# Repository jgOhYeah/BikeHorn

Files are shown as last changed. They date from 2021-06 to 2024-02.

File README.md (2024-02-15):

# BikeHorn
A "musical" siren for bicycles.
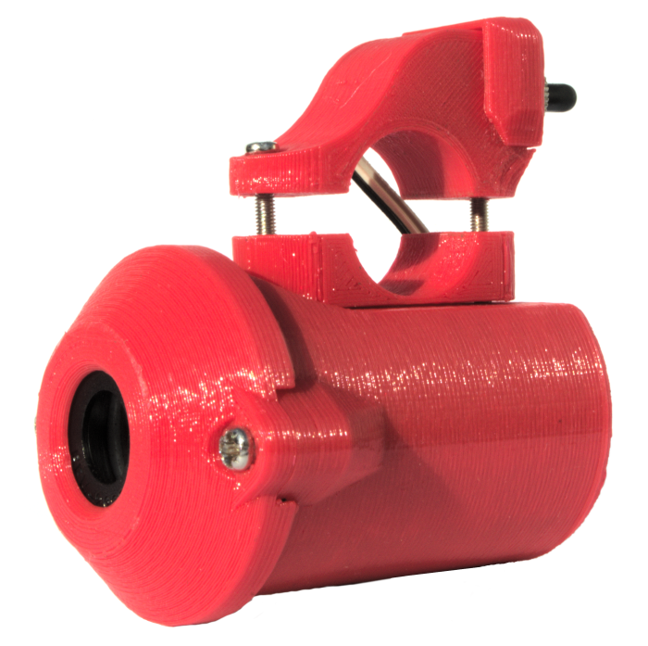
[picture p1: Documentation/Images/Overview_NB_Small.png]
Overview photo of the horn from an angle


This design was published in the Circuit Notebook section of the [Februrary 2022 issue](https://www.siliconchip.com.au/Issue/2022/February) of the Silicon Chip magazine. Feel free to have a look there if you would like a nice explanation / writeup of the horn's operations and construction.

## Main steps for building and usage
1. Modify the Arduino nano for low power and low voltage usage.
2. Build the circuit - see [BikeHornPCB](BikeHornPCB) for a PCB design. The siren is from an old smoke alarm.
3. 3D print the case.
4. Optimise parameters for each note to be the loudest possible - see [Tuning](Tuning) for details.
5. Generate the tunes to play using [this Musescore plugin](https://github.com/jgOhYeah/TunePlayer/blob/main/extras/MusescorePlugin.md). Paste this into `tunes.h` in the main [BikeHorn sketch](BikeHorn).
6. Upload to the Arduino and test.
7. Mount on bicycle / vehicle and have fun.

See the Silicon Chip section or the [Images directory](Documentation/Images) for relevent diagrams and images of the horn.

A low resolution gif that gives an idea of order of assembly:  
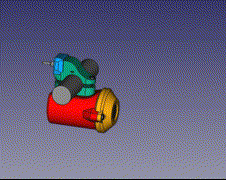
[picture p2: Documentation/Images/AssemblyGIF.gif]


## Extensions
I have attempted to make the firmware fairly modular and most non-core parts have been included as externsions. This allows for easier maintenance and customisation. For more details on enabling, disabling and writing extensions, please see the [extensions documentation](Documentation/Extensions.md).

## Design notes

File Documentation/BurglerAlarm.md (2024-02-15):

# Burgler Alarm

## State machine
```mermaid
graph TD;
    StateInit((StateInit)) -- Delay --> StateSleep
    StateSleep -- Angle / Acceleration change --> StateAwake
    StateAwake -- Otherwise --> StateAwake
    StateAwake -- Angle / Acceleration change --> StateAlert
    StateAlert -- Timeout --> StateSleep
    StateAlert -- Angle / Acceleration change --> StateCountdown
    StateCountdown -- Pin correct --> Exit((Exit))
    StateCountdown -- Timed out --> StateSiren
    StateSiren -- Pin correct --> Exit
    StateSiren -- Time out --> StateSleep
```

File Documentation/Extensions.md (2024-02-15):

# Extensions
I have attempted to make the firmware fairly modular and most non-core parts have been included as externsions. This allows for easier maintenance and customisation.

## Extensions overview
All files relating to extensions are in the `src/extensions` folder of the firmware. `extensionsManager.h` contains the framework for the extensions system and `extensions.h` includes and specifies which extensions are enabled.

## Using extensions / menu system
Each extension will behave slightly differently. Some extensions may need to have functionality activated / run on command. This is addressed through a menu system.

To enter the menu, press the change tune button for more than two seconds. The next item can be selected by short pressing the change tune button. If this button has been pressed more times than there are items, the menu will go back to the start and play a short beep. To select an item, long press the change tune button.

If at any time, the horn button is pressed, the menu will be exited and the horn will sound. This is for safety reasons to keep the horn sound available as much as possible.

## Adding and removing an extension
To add an extension, modify `extensionsManager.h`.

Include the extension header file and create an instance:
```c++
#include "exampleExtension.h"
ExampleExtension exampleExtension;
```

Add a reference to the instance to the array of extensions:
```c++
Extension* extensionsList[] = {
    &exampleExtension,
    // ... Other extension instances
};
```
The order in this array affects the order that extensions are called for each hook and the order that they appear in the menu if they have menu items.

## Existing extensions
- **[Burgler alarm](BurglerAlarm.md)** - Uses an accelerometer to sound the siren if disturbed.
- **Example extension** - Demonstrates how extensions may be implemented.
- **Log run time** - Logs how many times and for how long the horn is used to EEPROM for battery life estimates.
- **Measure battery** - Prints the battery voltage to the serial console every so often.
- **MIDI synth** - Allows the horn to function as a MIDI synth.
- **SOS** - Plays the morse SOS tone indefinitely when selected from the menu.

## Extension structure
Each extension is a class that inherits the `Extension` class. This has a number of methods that can be overridden and are called on certain events occuring, such as on startup, waking up and playing tunes.

```mermaid
classDiagram
    ExtensionManager "1" --> "1" Array
    Extension "1" --> "1" Array
    Extension "0..*" --> "1" MenuItem
    ExtensionManager "1" --> "0..*" Extension
    Extension <|-- ExampleExtension

    class Array~Type~ {
        <<struct>>
        +Type* array
        +uint8_t length
    }

    class MenuItem {
        <<typedef>>
    }

    class Extension {
        <<abstract>>
        +onStart()
        +onWake()
        +onSleep()
        +onTuneStart()
        +onTuneStop()
        +Array~MenuItem~ menuActions
    }

    class ExtensionManager {
        +callOnStart()
        +callOnWake()
        +callOnSleep()
        +callOnTuneStart()
        +callOnTuneStop()
        +displayMenu()
        -Array~Extension*~ extensions
    }

    class ExampleExtension {

    }
```

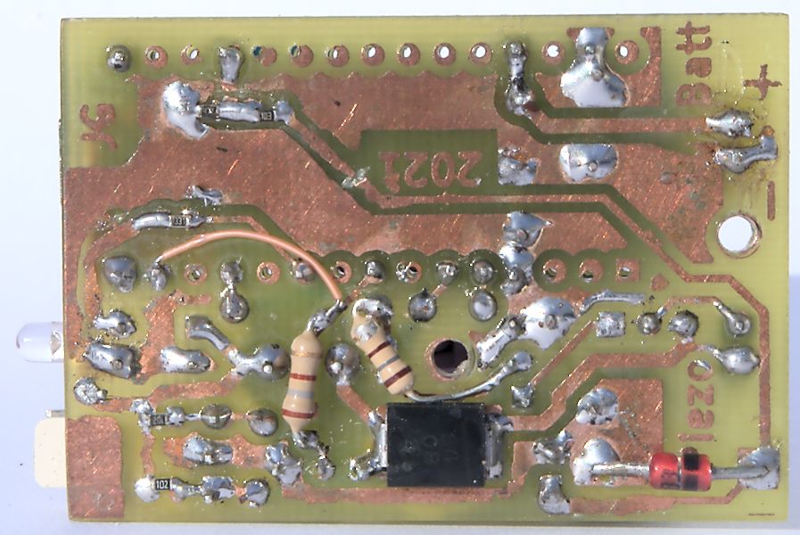
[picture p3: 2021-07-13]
Documentation/Images/PCB_Back.jpg

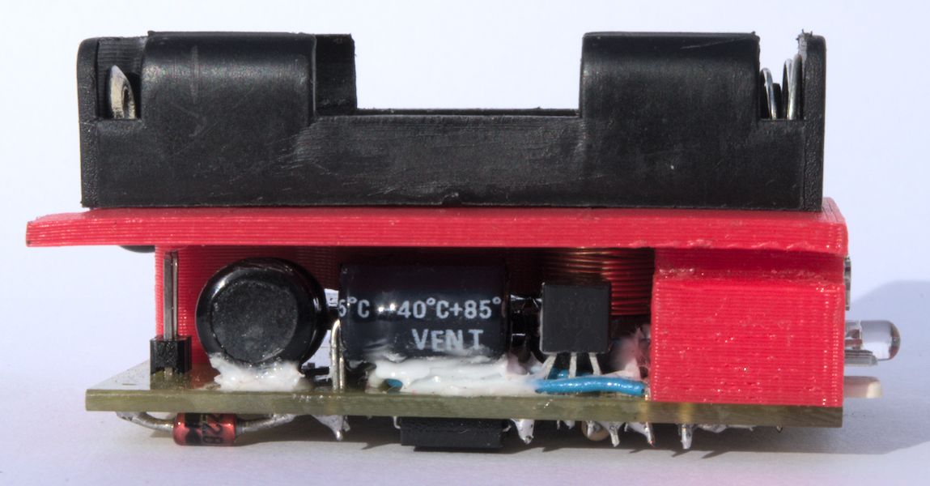
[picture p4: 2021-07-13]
Documentation/Images/Tray_Side.jpg

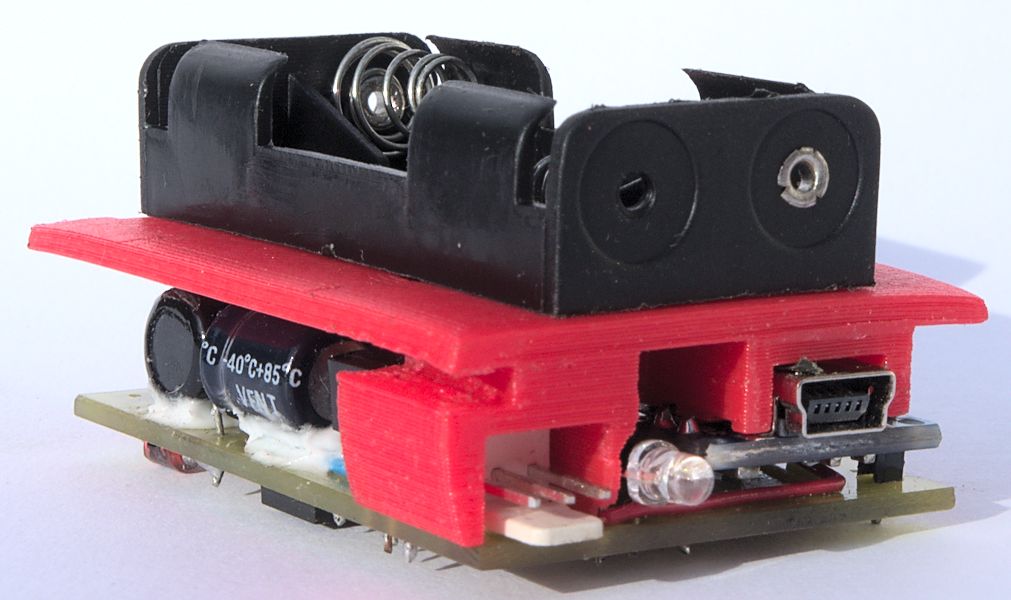
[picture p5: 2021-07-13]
Documentation/Images/Tray_Angle.jpg

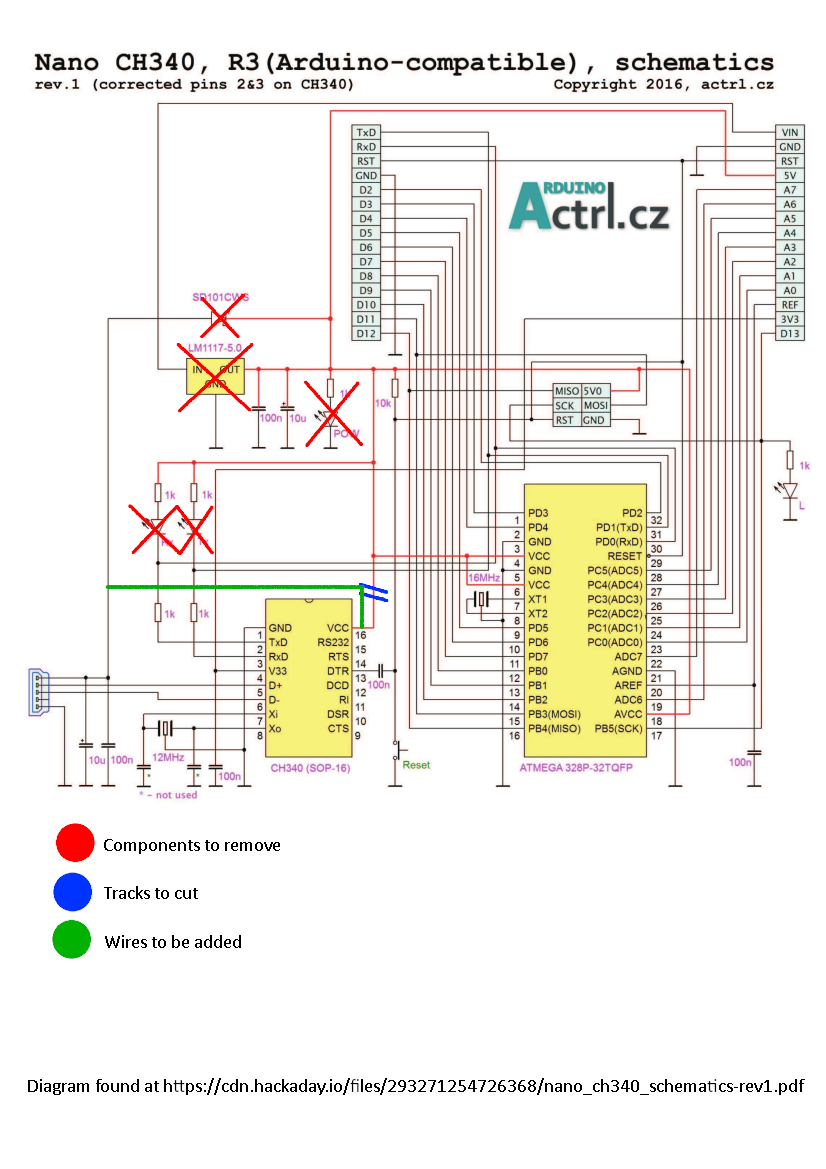
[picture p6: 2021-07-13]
Documentation/Images/ArduinoNanoModifications.png

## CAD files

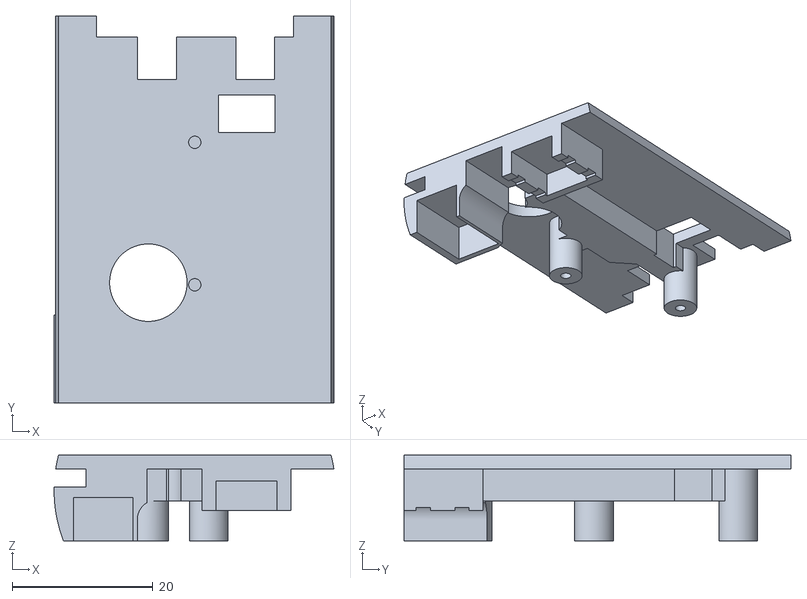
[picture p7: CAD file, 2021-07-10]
Case/MainBody-CarrierFrame.stl
39.8 x 55.0 x 12.2

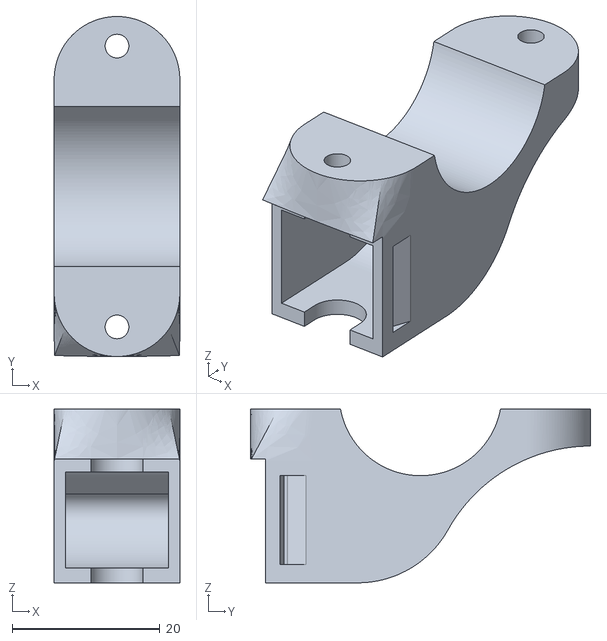
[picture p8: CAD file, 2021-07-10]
Case/MainBody-HandlebarClampSwitch.stl
17.0 x 46.0 x 23.5

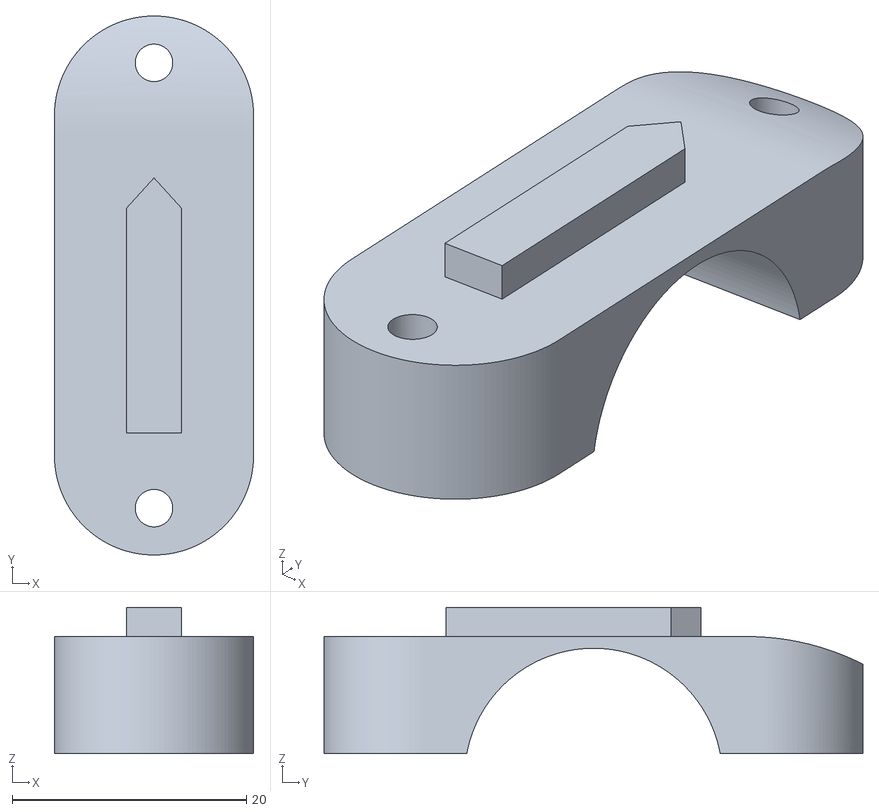
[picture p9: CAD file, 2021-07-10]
Case/MainBody-HandlebarGuide.stl
17.0 x 46.0 x 12.5

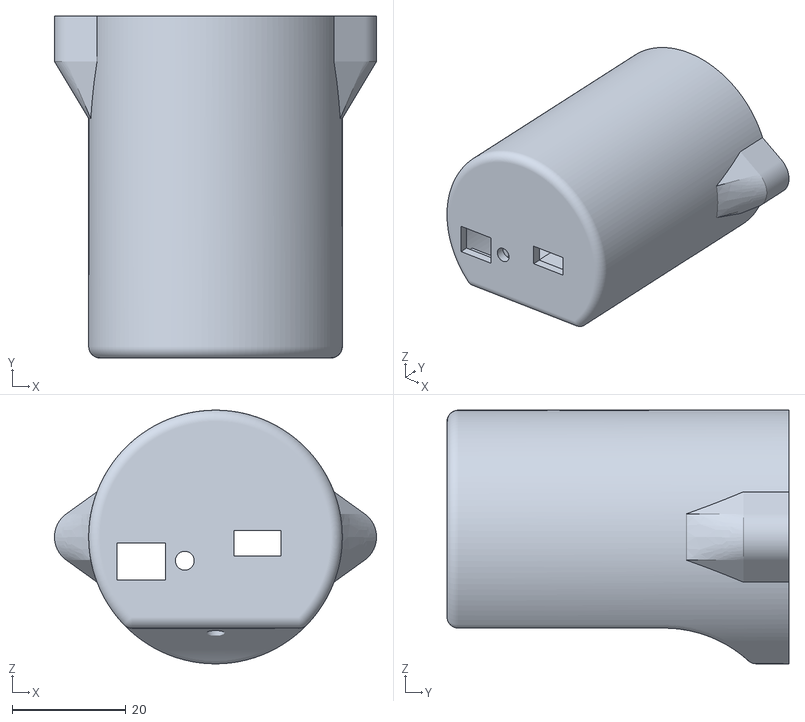
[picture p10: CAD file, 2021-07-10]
Case/MainBody-MainBody.stl
56.5 x 60.0 x 44.5

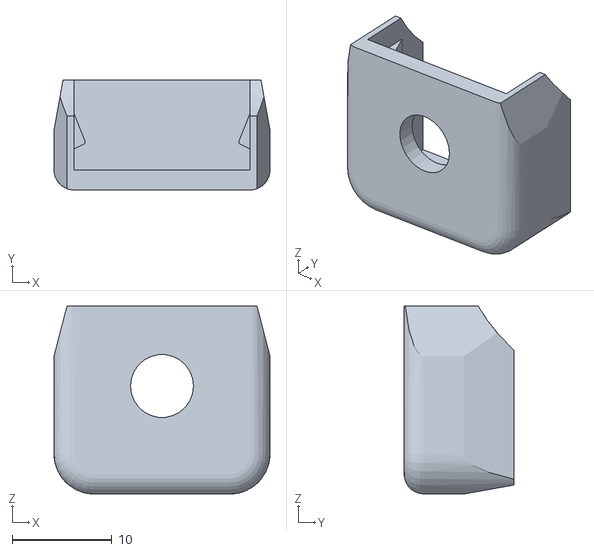
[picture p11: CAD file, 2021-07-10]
Case/MainBody-SwitchCover.stl
21.6 x 11.0 x 18.8

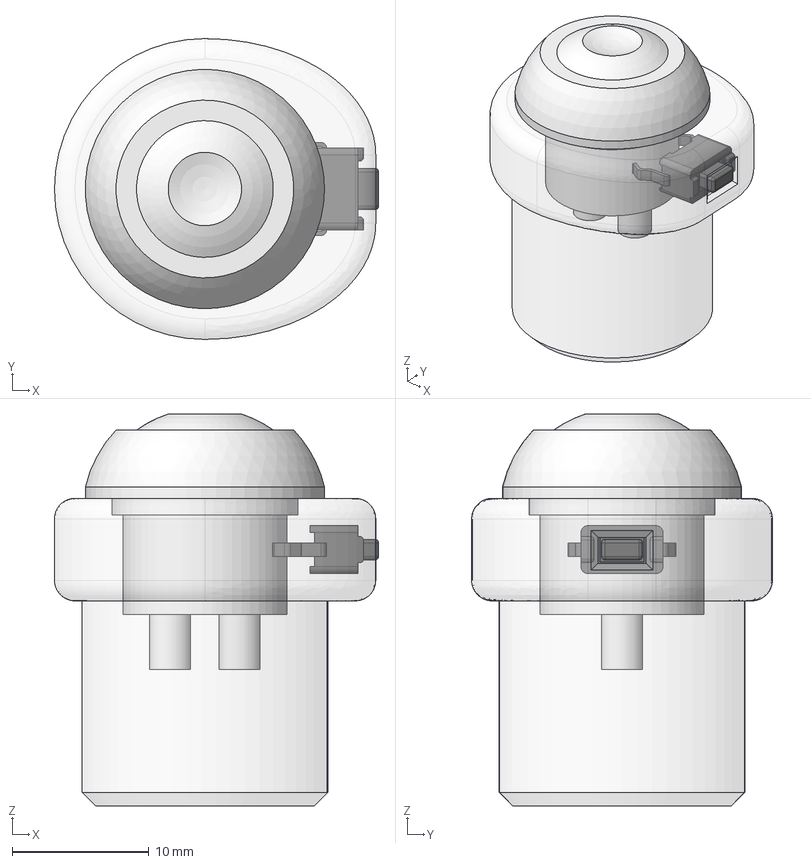
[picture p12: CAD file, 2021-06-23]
Case/HandlebarButton.FCStd
23.7 x 22.0 x 28.7 mm
Button
Mount
TactileSW

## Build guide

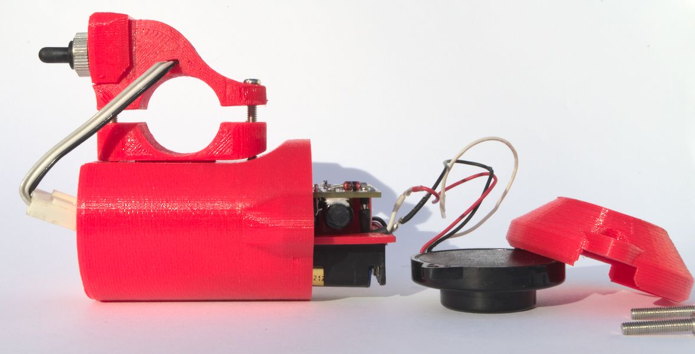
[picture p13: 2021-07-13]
Documentation/Images/PartlyDisassembled.jpg

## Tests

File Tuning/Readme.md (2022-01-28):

I find piezo sirens to be fairly fussy and unpredictable when trying to make them loud, especially across a broad range of frequencies. To help with this, I have written a small application to vary a couple of parameters under the horn's control and measure the resulting volume of the siren using a laptop / computer microphone. The data is then analysed and converted into a series of straight lines before being uploaded to the EEPROM of the Arduino in the horn.

This application is a python script and has been tested on Windows and Linux (Ubuntu), but should also work on Macintosh / other operating systems as long as the required libraries are installed.

> **Note:** This optimiser, the files it produces / uses and the way data is stored on the horn itself is in no way compatible with the earlier `SoundLevel.py` and `DisplayData.py` scripts. If you want to use or access these tools, you will need to use an [earlier release](https://github.com/jgOhYeah/BikeHorn/releases/tag/v1.0.0).

# Table of contents <!-- omit in toc -->
- [Installation](#installation)
- [Main Steps](#main-steps)
  - [Initial setup and running a test](#initial-setup-and-running-a-test)
  - [Saving and loading test results](#saving-and-loading-test-results)
  - [Interpreting and viewing test results](#interpreting-and-viewing-test-results)
  - [Optimising the test results](#optimising-the-test-results)
  - [Uploading the settings to the horn](#uploading-the-settings-to-the-horn)
  - [Tidying up and making the horn usable](#tidying-up-and-making-the-horn-usable)
- [Advanced features and debugging](#advanced-features-and-debugging)
- [Troubeshooting](#troubeshooting)
- [Questions that may or may not be asked, let alone frequently asked](#questions-that-may-or-may-not-be-asked-let-alone-frequently-asked)
# Installation
The application requires python 3 along with a few non built-in libraries. Assuming you already have python 3, the libraries can be installed with
```bash
pip3 install numpy sounddevice pyserial piecewise-regression matplotlib
```
Download this repository or at the very least [`BikeHornOptimiser.py`](BikeHornOptimiser.py) and the [corresponding Arduino sketch](OptimiserSketch).

# Main Steps
## Initial setup and running a test
1. Upload the [Optimiser Sketch](OptimiserSketch) to the horn.
2. Find a quiet place to make not very quiet for the next little while.
3. Run [`BikeHornOptimiser.py`](BikeHornOptimiser.py). In the terminal, this will be something like `python3 BikeHornOptimiser.py`. On Windows, this seems to be a little slow in starting. If no window appears, attempt to run the script from the terminal and see if there is any error messages or missing libraries reported. A window should appear looking something like this:  
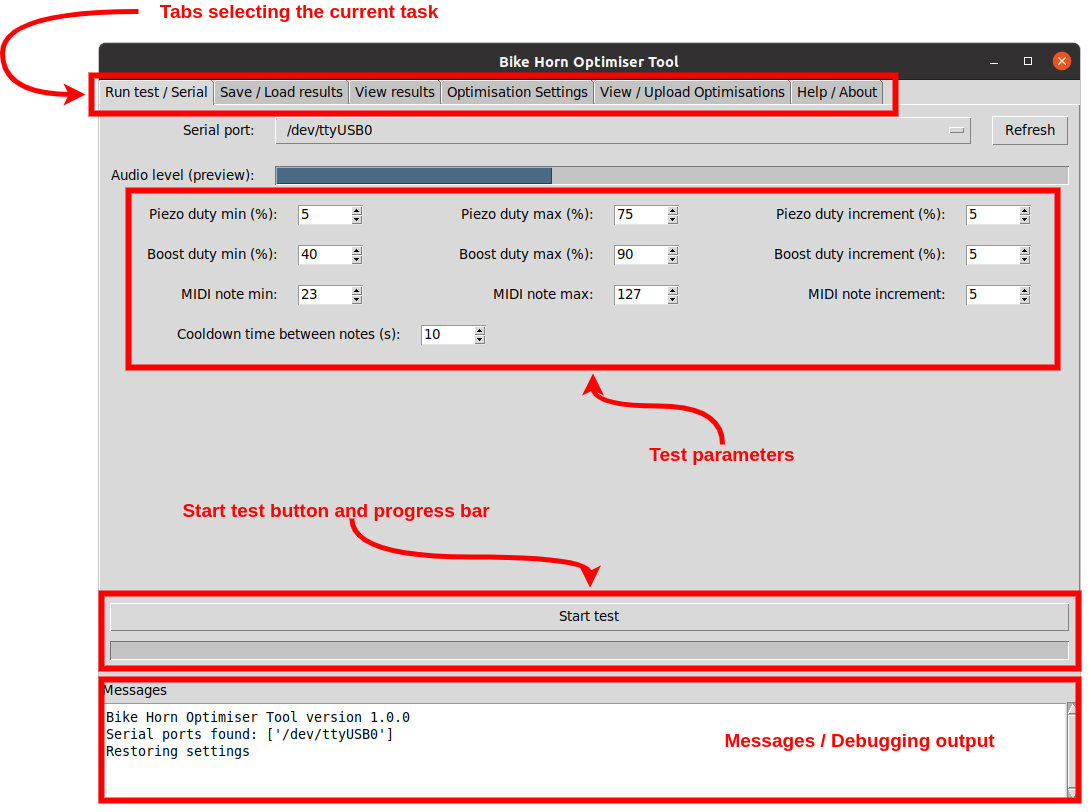
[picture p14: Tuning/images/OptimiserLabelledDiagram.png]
Labelled diagram of the bike horn optimiser application, showing the tabbed layout

4. If you have existing test data with settings you would like to reuse, open this file using the *Save / Load results* tab (see the [Saving and loading test results](#saving-and-loading-test-results).
5. Navigate to the *Run Test / Serial* tab (you will be on it by default). Connect the horn to the computer using a mini usb cable and select its serial port (something like `COM6` on Windows and `/dev/ttyUSB0` or `/dev/ttyACM0` on other operating systems). Try clicking the *Refresh* button if the serial port is not listed.
6. Edit the parameters for which to run the test with. These allow you to specify the ranges of duty cycles to test for driving the piezo siren and driving the voltage boosting stage, as well as the amount to increment these values between each test. You can also select what range of MIDI notes to test and allow the horn to cool down for a few seconds in between testing each MIDI note.
7. When ready, click *Start test*. If it is greyed out, no serial port is selected. Select the horn's serial port and try again. All going well, the horn should start making noises a few seconds later. The message box will print an estimate of the time that the test will take followed by the progress

## Saving and loading test results
Test results can be saved and loaded from a file so that the results can be analysed and uploaded at a different time to when the test is run. In case of crashes or unexpected interruptions when running a test, a backup file is saved after testing each note. This has the same name at the currently opened file (or one based off the time the application was started if nothing was opened) with "BACKUP" appended to the end.

Use the *Open* button to open a file, loading stored settings and test data and the *Save as* button to save all existing settings and test data. Opening a file will clear any existing, unsaved data.

## Interpreting and viewing test results
The *View results* tab contains a 3D surface plot for each note showing the percieved loudness as each of the two parameters of the duty cycle for the piezo element and the boost stage are varied. The optimal settings of these duty cycles are the highest point on the loudnes scale (marked by an orange dot). The scroll bar below the graph can be used to adjust the data for which note is displayed. Some notes will have a nice, clean surface such as this example:  
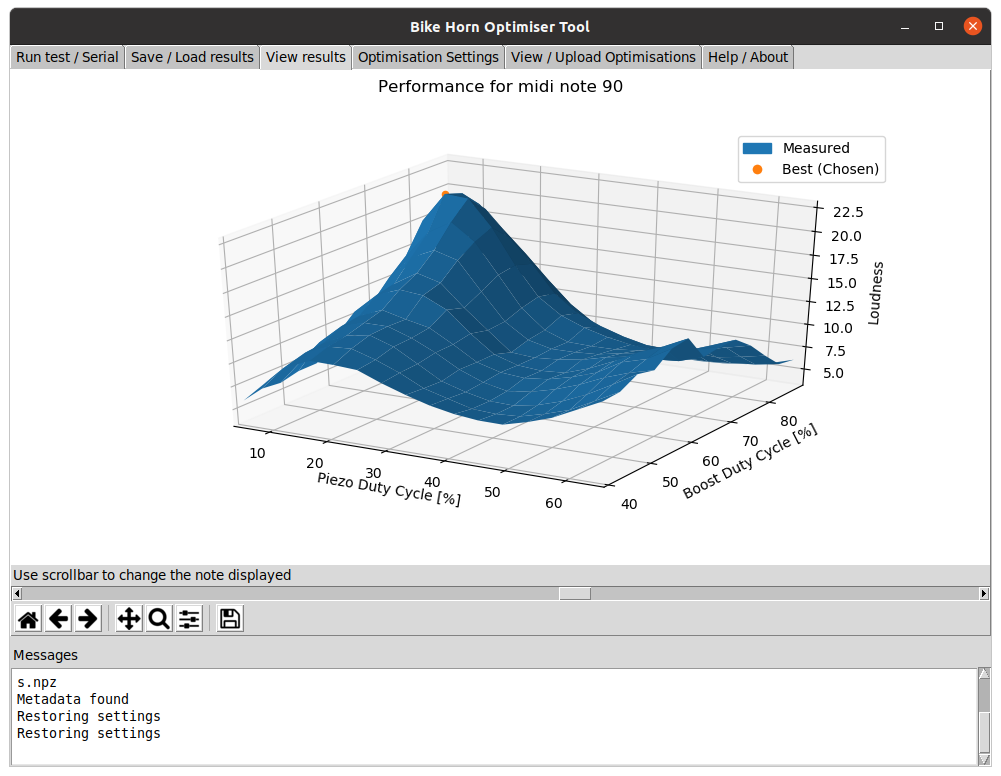
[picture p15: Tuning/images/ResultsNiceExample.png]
Screenshot of the results tab for midi note 90 of a test showing a nice smooth surface
  
Other notes appear much noisier in their data. The aim is to reduce this noise as much as possible, although I'm not quite sure how to do this at the moment apart from trying to minimise background noise during the testing process.

The *Optimisation settings* tab shows the settings picked as optimal for each midi note (i.e. the settings for the orange dot in the *View results* tab for each midi note). An example of this is shown below:  
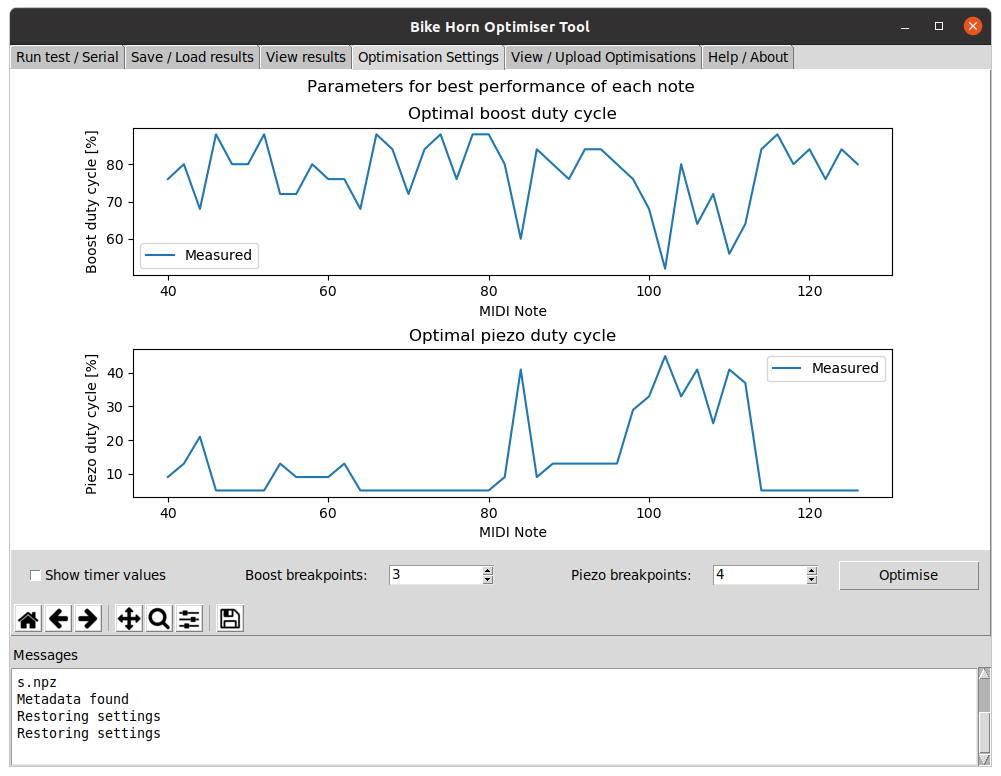
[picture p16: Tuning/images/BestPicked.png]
Screenshot of the Optimisation Settings tab showing the settings chosen as optimal for each midi note


## Optimising the test results
Once you have some testing data, navigate to the *Optimisation Settings* tab and click *Optimise*. After a few seconds, a couple of orange lines should appear, courtesy of the [piecewise-regression](https://github.com/chasmani/piecewise-regression/) library. These approximate the measured data. Feel free to play around with the number of breakpoints, set using the number entry boxes below the graph, to produce approximations that most closely match the measured data. An example is shown below:  
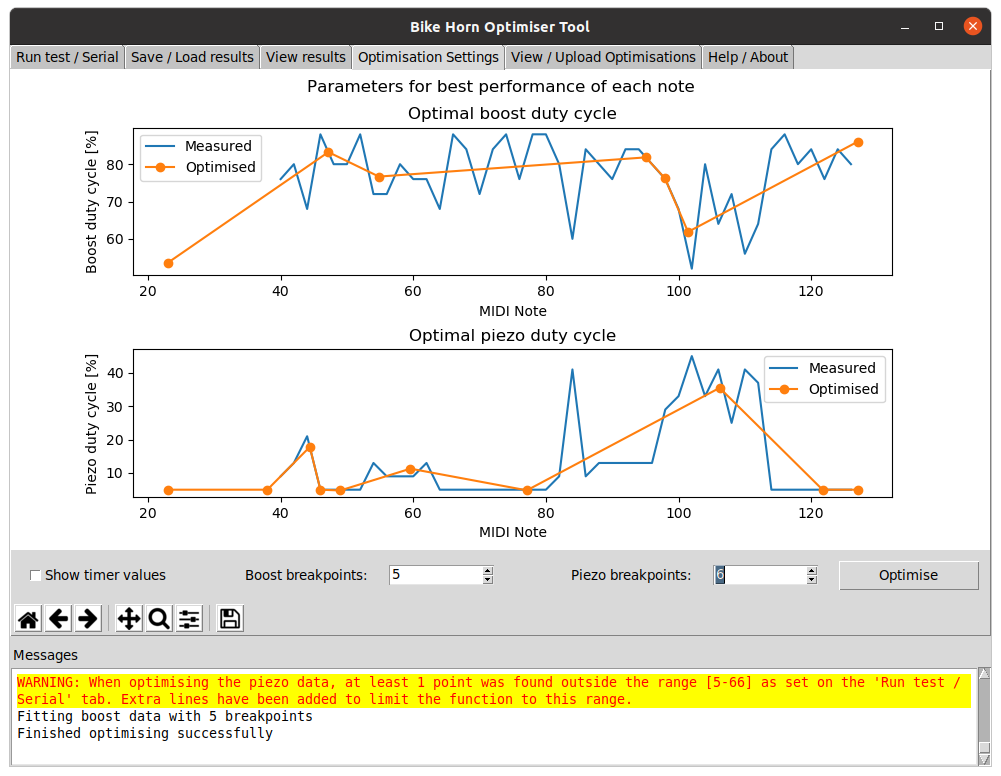
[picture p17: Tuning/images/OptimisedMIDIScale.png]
Screenshot of the optimisation window with midi scale and orange lines
  
Due to some of the randomness involved in fitting lines to the data, for higher numbers of breakpoints, it may take multiple attemts to get the results to "converge" and thus find an acceptable solution, if they do at all.

Internally, the horn uses the maximum value the piezo timer (timer 1) counts to as the x axis instead of the midi note and the compare value for the relevent timer instead of the duty cycle. If you would like to view the data using these scales, tick the *Show timer values* checkbox belows the graphs. An extra green line will be displayed on each graph. This represents the actual linear lines that will be uploaded to the horn, allowing for integer maths and limited space available to store the relevent numbers. An example is shown below:  
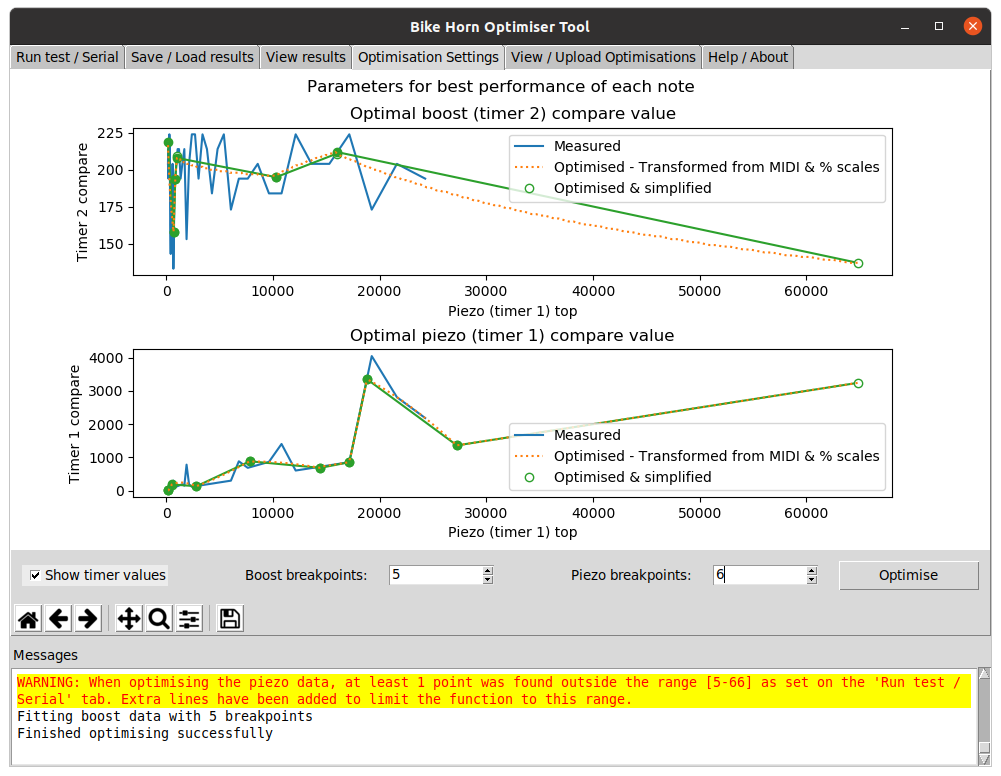
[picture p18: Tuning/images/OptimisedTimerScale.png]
Screenshot of the optimisation window with midi scale and orange and green lines


## Uploading the settings to the horn
As shown below, the top two text boxes in the *View / Upload optimisations* tab show my attempt at drawing piecewise function representations of the settings that will be uploaded. The final text box shows the raw data that will be uploaded to the EEPROM in the horn, mainly for curiosity's sake.  
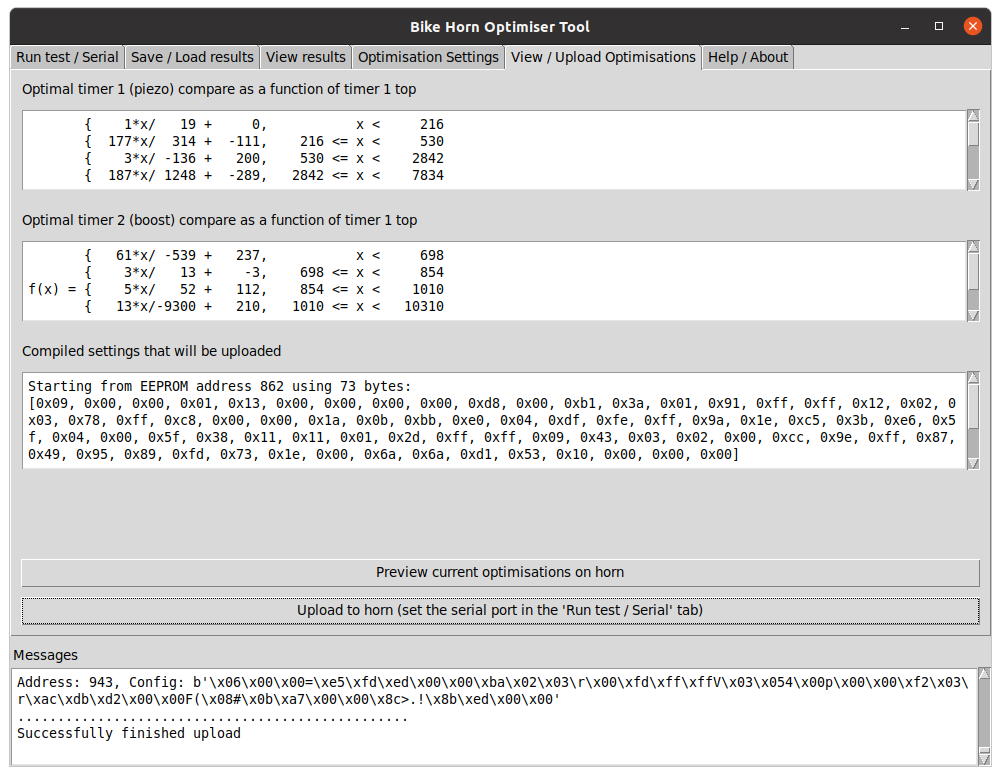
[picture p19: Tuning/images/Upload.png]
Screenshot of the upload tab showing the text boxes with the piecewise functions and raw data to upload


Make sure the horn is connected and the serial port is set correctly on the *Run test / Serial* tab. Now click the *Upload to horn* button. All going well, the settings will be uploaded to the horn.

## Tidying up and making the horn usable
Flash the main [bike horn sketch](../BikeHorn/) to make the horn usable again and to put it back into power saving mode so that it will not flatten any installed batteries if left sitting for too long.

# Advanced features and debugging
## Previewing settings before uploading them <!-- omit in toc -->
A preview tool has been included to allow easier experimentation with settings before uploading them to the horn's EEPROM. This can be accessed from the *Preview current optimisations on horn* button in the *View / Upload optimisations* tab. This will display a new window as shown below, allowing single notes or a range of midi notes to be played with selectable duty cycles for the piezo element and boost stage.  
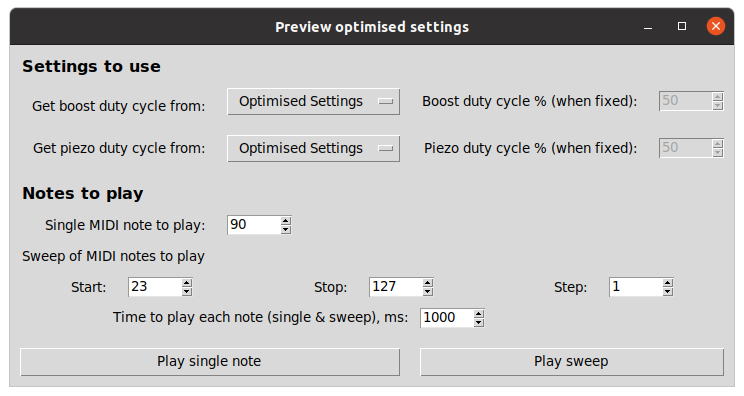
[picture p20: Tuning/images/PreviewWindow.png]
Screenshot of the preview window


## Dumping the contents of the EEPROM <!-- omit in toc -->
Connect the horn and click the *Dump EEPROM of a connected horn* button in the *Help / About* tab.

## Erasing the EEPROM <!-- omit in toc -->
Connect the horn and click the *Wipe EEPROM of a connected horn* button in the *Help / About* tab.

# Troubeshooting
## The serial port does not appear <!-- omit in toc -->
Check whether other software such as the Arduino IDE can see the serial port. Make sure no other programs have it open or are currently using it.

## "Did not get a response from the horn" message <!-- omit in toc -->
Are you using the correct serial port and is the [Optimiser sketch](OptimiserSketch/) uploaded to the horn? Also make sure no other software is currently using the serial port. If this doesn't work, try unplugging and replugging in the usb cable.

## Arduino not resetting or misbehaving after using this application <!-- omit in toc -->
Try unplugging and replugging in the usb cable.
## Application freezes when trying to close it <!-- omit in toc -->
This is a bug I have not worked out yet - something to do with the audio level monitoring. If you are running the application in a terminal, try using *Control-C* a couple of times. If that doesn't work or you aren't using a terminal, kill the program using the task manager.

# Questions that may or may not be asked, let alone frequently asked
## Why store the optimised settings in EEPROM? <!-- omit in toc -->
The original optimisation scripts outputted C++ code to paste into the [Bike horn Arduino sketch](../BikeHorn). While this does work for one horn, I could see this becoming a problem if more than one horn is ever built, as you would end up with code that needs to be customised for each horn and then kept track of through updates and changing of the installed tunes, making it messy to deal with. Instead, the aim of storing the optimised settings in EEPROM is that the settings live with the horn rather than the source code, meaning that the same source code can theoreticaly be used with every horn in existance and they should all perform optimally as far as selecting the best duty cycles of each stage. Tunes may still need to be transposed to suit each horn's preferred frequency range though.

## Why is the optimising sketch not a part of the main bike horn sketch? <!-- omit in toc -->
The aim of optimising is that it doesn't need to be done all that often. Seeing as the tunes are stored as part of the program, the horn will need to be reprogrammed whenever the installed tunes are uploaded, so it is not much of an extra burden to upload a special optimising sketch. It is also one less thing to potentially go wrong in the main sketch and besides, it allows even more room for tunes 😉.

## Why the limit of 10 lines (9 breakpoints) per parameter to optimise? <!-- omit in toc -->
The processed optimisations are stored in EEPROM in the Arduino microcontroller on the horn. This is limited to 1024 bytes on an Arduino Nano. Each linear function takes up 8 bytes. Because (as an optional feature) the EEPROM is also used for tracking the number of times and for how long the horn is used for battery life monitoring, this resource needs to be shared. Feel free to adjust the parameters for the amount and addresses to allocate in the source code of this optimiser and 'defines.h' of the main bike horn sketch, making sure that they are in agreement for things to work as expected.

## Why did the battery go flat after optimising? <!-- omit in toc -->
Unlike the main bike horn sketch, she optimiser sketch does not contain any power saving features. Thus, when taking a break or leaving the horn sit, make sure to reflash the main [bike horn sketch](../BikeHorn) or take the batteries out.

## Why is the lowest midi note 23? <!-- omit in toc -->
This is due to the internal hardware and setup of the timers in the horn. Timer 1 is used to provide the frequency of the note to play by starting from 0 and counting up to a specified number before resetting back to 0. The time for this to happen is the period of the wave and thus the lower the note, the larger this number must be. Timer 1 is a 16 bit timer, meaning the maximum value it can count up to is *2^16-1 = 65535*, meaning that without mucking around with prescalars and clock speeds, midi note 23 is the lowest note where the value to count to is below 65535.

Note that this is a very low note for a piezo siren and is more a series of clicks anyway - not much use for a horn, let alone anything lower.

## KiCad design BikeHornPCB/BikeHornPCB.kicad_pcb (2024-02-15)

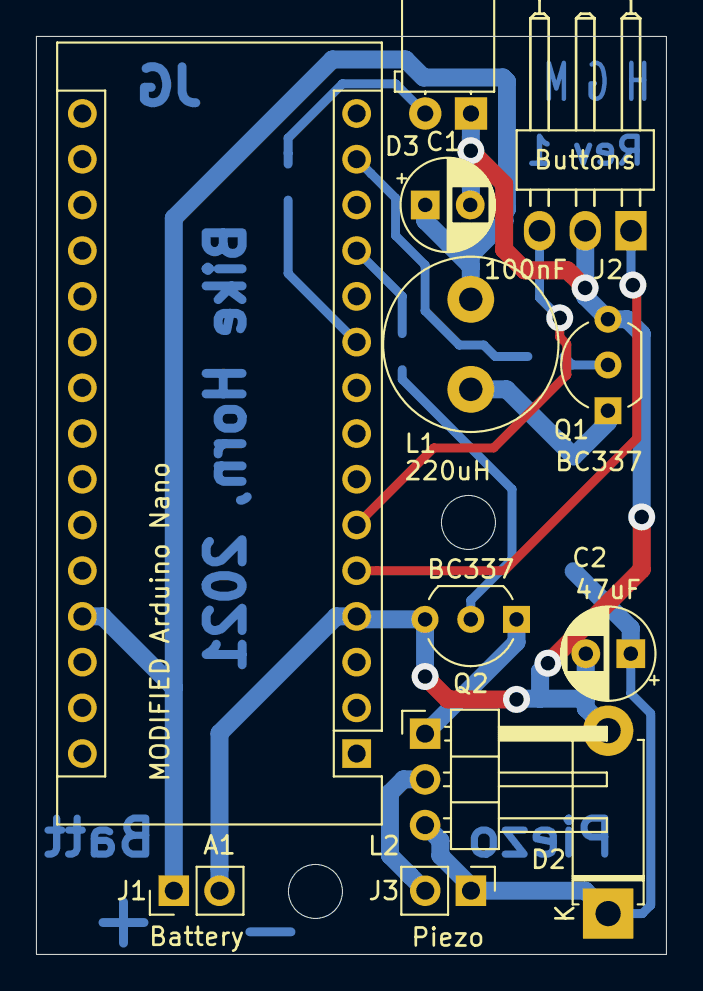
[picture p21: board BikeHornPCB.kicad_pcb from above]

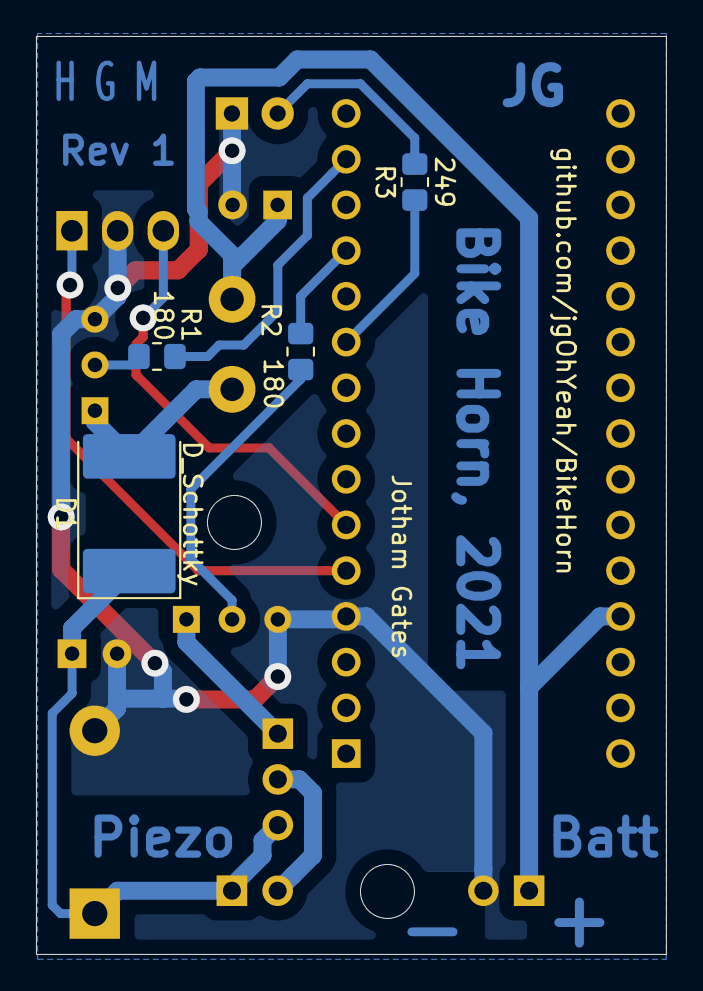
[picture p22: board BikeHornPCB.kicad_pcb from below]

Board: 2 copper layers, 35.0 x 51.0 mm, 16 parts (4 on the bottom side), 14 nets.

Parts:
A1: MODIFIED Arduino Nano; Arduino_Nano
C1: 100nF; CP_Radial_D5.0mm_P2.50mm
C2: 47uF; CP_Radial_D5.0mm_P2.50mm
D1: D_Schottky; D_3220_8050Metric
D2: 22V; D_5W_P10.16mm_Horizontal
D3: LED; LED_D5.0mm_Horizontal_O1.27mm_Z3.0mm
J1: Battery; PinHeader_1x02_P2.54mm_Vertical
J2: Buttons; Molex_KK-254_1x03_P2.54mm_Horizontal
J3: Piezo; PinHeader_1x02_P2.54mm_Vertical
L1: 220uH; L_Radial_D9.5mm_P5.00mm_Fastron_07HVP
L2: PiezoDriverCoil; PinHeader_1x03_P2.54mm_Horizontal
Q1, Q2: BC337; TO-92_Inline_Wide
R1, R2: 180; R_0805_2012Metric_Pad1.20x1.40mm_HandSolder
R3: 249; R_0805_2012Metric_Pad1.20x1.40mm_HandSolder

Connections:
+BATT: A1.27, C1.1, J1.1, L1.1
GND: A1.4, C1.2, C2.2, D2.2, D3.1, J1.2, J2.2, Q1.3, Q2.3
unnamed: A1.5, J2.1
unnamed: A1.6, J2.3
unnamed: A1.10, R3.1
unnamed: A1.12, R2.2
unnamed: A1.14, R1.2
unnamed: C2.1, D1.1, D2.1, J3.1, L2.3
unnamed: D1.2, L1.2, Q1.1
unnamed: D3.2, R3.2
unnamed: J3.2, L2.2
unnamed: L2.1, Q2.1
unnamed: Q1.2, R1.1
unnamed: Q2.2, R2.1

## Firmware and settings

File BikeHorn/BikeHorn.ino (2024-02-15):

/** BikeHorn.ino
 * Source code for the BikeHorn.
 * 
 * For more details, see README.md or go to
 * https://github.com/jgOhYeah/BikeHorn
 * 
 * Written by Jotham Gates
 * Last modified 27/01/2023
 * 
 * Requires these libraries (can be installed through the library manager):
 *   - Low-Power (https://github.com/rocketscream/Low-Power) - Shuts things down to save power.
 *   - TunePlayer (https://github.com/jgOhYeah/TunePlayer) - Does most of the heavy lifting playing the tunes.
 *   - Queue (https://github.com/SMFSW/Queue) - Required by TunePlayer.
 * 
 * Only required if LOG_RUN_TIME is defined:
 *   - EEPROMWearLevel (https://github.com/PRosenb/EEPROMWearLevel) - Logs to EEPROM.
 */

#include "defines.h"

// Prototypes so that the extension manager is happy
void uiBeep(uint16_t* beep);
void uiBeepBlocking(uint16_t* beep);
void revertToTune();
uint32_t modeButtonPress();
void startBoost();
inline void stopBoost();
void sleepGPIO();
void wakeGPIO();

#include "tunes.h"
#include "src/optimisations.h"
#include "src/soundGeneration.h"
#include "src/soundGenerationStatic.h"

FlashTuneLoader flashLoader;
BikeHornSound piezo;
TunePlayer tune;
uint8_t curTune = 0;
period_t sleepTime = SLEEP_FOREVER;

#ifdef ENABLE_WARBLE
Warble warble;
extern void uiBeep();
#endif

volatile Buttons wakePin;

#include "src/extensions/extensions.h"

void setup() {
    WATCHDOG_ENABLE;
    sleepGPIO(); // Shutdown the timers if the horn crashed previously
    wakeGPIO();
    Serial.println(F(WELCOME_MSG));
    Serial.print(F("There are "));
    Serial.print(tuneCount);
    Serial.println(F(" tunes installed"));

    // Tune Player
    flashLoader.setTune((uint16_t*)pgm_read_word(&(tunes[curTune])));
    tune.begin(&flashLoader, &piezo);
    tune.spool();

    // Extensions
    extensionManager.callOnStart();

#ifdef ENABLE_WARBLE
    /// Warble mode
    warble.begin(&piezo, WARBLE_LOWER, WARBLE_UPPER, WARBLE_RISE, WARBLE_FALL);
#endif
}

void loop() {
    // Go to sleep if not pressed and wake up when a button is pressed
    if(!IS_PRESSED(BUTTON_HORN)) {
        // Wait for tune (beep) to finish before sleeping.
        while(tune.isPlaying()) {
            tune.update();
            WATCHDOG_RESET;
            if (IS_PRESSED(BUTTON_HORN)) {
                // On rare occasions when the button is pressed during a beep, go to sleep and wake up again quickly.
                tune.stop();
                break;
            }
        }
        Serial.println(F("Going to sleep"));
        extensionManager.callOnSleep();
        sleepGPIO();
        wakeUpEnable();
        WATCHDOG_DISABLE;
        LowPower.powerDown(sleepTime, ADC_OFF, BOD_OFF); // The horn will spend most of its life here
        wakeUpDisable();
        WATCHDOG_ENABLE;
        wakeGPIO();
        Serial.println(F("Waking up"));
        extensionManager.callOnWake();
    } else {
        wakePin = PRESSED_HORN;
    }

    // If we got here, a button was pressed
    if(wakePin == PRESSED_HORN) {
        // Play a tune
        extensionManager.callOnTuneStart();
        // Start playing
        startBoost();
#ifdef ENABLE_WARBLE
        if(curTune != tuneCount) {
            // Normal tune playing mode
            tune.play();
        } else {
            // Warble mode
            warble.start();
        }
#else
        tune.play();
#endif

        // Play until the button has not been pressed in the past DEBOUNCE_TIME ms.
        digitalWrite(LED_EXTERNAL, HIGH);
        bool ledState = true;

        uint32_t startTime = millis();
        uint32_t curTime;
        uint32_t ledStart = startTime;
        do {
            WATCHDOG_RESET;

#ifdef ENABLE_WARBLE
            // Update warbling or the tune
            if(curTune != tuneCount) {
                tune.update();
            } else {
                warble.update();
            }
#else
            // Update the tune
            tune.update();
#endif

            // Flash the LED every so often
            if(curTime - ledStart > 125) {
                ledStart = curTime;
                digitalWrite(LED_EXTERNAL, !ledState);
                ledState = !ledState;
            }

            // Check if the button is pressed and reset the time if it is.
            if(IS_PRESSED(BUTTON_HORN)) {
                startTime = curTime;
            }
            curTime = millis();
        } while (curTime - startTime < DEBOUNCE_TIME);

        // Stop playing the tune
#ifdef ENABLE_WARBLE
        if(curTune != tuneCount) {
            tune.stop();
            tune.spool();
        } else {
            warble.stop();
        }
#else
        tune.stop();
        tune.spool();
#endif
        extensionManager.callOnTuneStop();

    } else if (wakePin == PRESSED_MODE) {
        // Change tune as the other button is pressed
        digitalWrite(LED_EXTERNAL, HIGH);

        // Only let go once button is not pushed for more than DEBOUNCE_TIME
        uint32_t pressTime = modeButtonPress();

        // Was this a long or short press?
        if (pressTime < LONG_PRESS_TIME) {
            // Short press, change tune
            curTune++;
#ifdef ENABLE_WARBLE
            if(curTune > tuneCount) { // Use == for the warble mode
                curTune = 0;
            }
            if(curTune != tuneCount) {
                // Change tune as normal
#else
            if(curTune == tuneCount) {
                curTune = 0;
            }
#endif
                Serial.print(F("Changing to tune "));
                Serial.println(curTune);
                flashLoader.setTune((uint16_t*)pgm_read_word(&(tunes[curTune])));

                // Stop tune and setup for the next time
                tune.stop();
                tune.spool();
#ifdef ENABLE_WARBLE
            } else {
                // Don't do anything here and select on the fly
                Serial.println(F("Changing to warble mode"));
            }
#endif
        } else {
            // Long press, display menu for extensions
            extensionManager.displayMenu();
        }
    }
}

/**
 * Puts the GPIO into a low power state ready for the microcontroller to sleep.
 */
void sleepGPIO() {
    // Shut down timers to release pins
    TCCR1A = 0;
    TCCR1B = 0;
    stopBoost();

    // Shutdown serial so it won't be affected by playing with the io lines
    Serial.end();

    // Using registers so everything can be done at once easily.
    DDRB = bit(PB1) | bit(PB3); // Set everything except pwm to input pullup
#ifdef ACCEL_INSTALLED
    DDRC = ACCEL_PINS_SLEEP_MODE;
    PORTC = ACCEL_PINS_SLEEP_STATE; // Pull up unusec inputs, set everything else low.
#else
    DDRC = 0;
    PORTC = 0xff;
#endif

    // Pull all unused pins high to avoid floating and reduce power.
    DDRD = 0x03; // Set serial as an output to tie low
    PORTB = ~(bit(PB1) | bit(PB3));
    PORTD = 0xfc; // Don't pull the serial pins high
    
    // Keep as outputs
    pinMode(LED_EXTERNAL, OUTPUT);
    pinMode(LED_BUILTIN, OUTPUT);
    digitalWrite(LED_EXTERNAL, LOW);
    digitalWrite(LED_BUILTIN, LOW);
}

/**
 * Wakes and sets up the GPIO and peripheries.
 */
void wakeGPIO() {
    DDRD = 0x02; // Serial TX is the only output
    PORTD = 0x0E; // Idle high serial
    Serial.begin(SERIAL_BAUD);
    DDRB = bit(PB1) | bit(PB3);
    PORTB = 0x00; // Make sure everything is off
    pinMode(LED_EXTERNAL, OUTPUT);
    pinMode(LED_BUILTIN, OUTPUT);

    // Will leave waking the accelerometer up to its own code as it isn't needed often.
}

void wakeUpEnable() {
    wakePin = PRESSED_NONE;
    // Set interrupts to wake the processor up again when required
    attachInterrupt(digitalPinToInterrupt(BUTTON_HORN), wakeUpHornISR, LOW);
    attachInterrupt(digitalPinToInterrupt(BUTTON_MODE), wakeUpModeISR, LOW);
}

void wakeUpDisable() {
    detachInterrupt(digitalPinToInterrupt(BUTTON_HORN));
    detachInterrupt(digitalPinToInterrupt(BUTTON_MODE));
}

/**
 * Interrupt Service Routine (ISR) called when the hirn wakes up with the horn button pressed.
 */
void wakeUpHornISR() {
    wakePin = PRESSED_HORN;
}

/**
 * Interrupt Service Routine (ISR) called when the hirn wakes up with the mode button pressed.
 */
void wakeUpModeISR() {
    wakePin = PRESSED_MODE;
}

/**
 * Sets up and starts the intermediate boost stage.
 */
void startBoost() {
    // Set PB3 to be an output (Pin11 Arduino UNO)
    DDRB |= (1 << PB3);
    
    TCCR2A = (1 << COM2A1) | (1 << WGM21) | (1 << WGM20); // Mode 3, fast PWM, reset at 255
    TCCR2B = (1<< CS20); // Prescalar 1
    OCR2A = IDLE_DUTY; // Enough duty cycle to keep the voltage on the second stage at a reasonable level.
}

/**
 * @brief Stops timer 2, which controls the boost stage.
 * 
 */
inline void stopBoost() {
    TCCR2A = 0;
    TCCR2B = 0;
}

/**
 * @brief Waits until the mode button has been released and returns the time
 * it was pressed in ms. If the horn button is pressed at any time, returns 1.
 * 
 * @return uint32_t 
 */
uint32_t modeButtonPress() {
    // Only let go once button is not pushed for more than DEBOUNCE_TIME
    uint32_t pressTime = millis();
    uint32_t debounceTime = pressTime;
    while(millis() - debounceTime < DEBOUNCE_TIME) {
        WATCHDOG_RESET;
        tune.update();
        if(IS_PRESSED(BUTTON_MODE)) {
            debounceTime = millis();
        }

        // If the horn button is pressed, exit immediately to start playing a tune.
        if(IS_PRESSED(BUTTON_HORN)) {
            wakePin = PRESSED_HORN;
            return 1;
        }
    }
    return millis() - pressTime;
}

/**
 * @brief Stores the current tune, then starts playing a beep / other tune.
 * When this is finished, the original tune will be restored.
 * 
 * @param beep the new tune.
 */
void uiBeep(uint16_t* beep) {
    tune.stop();
    tune.setCallOnStop(revertToTune);
    flashLoader.setTune(beep);
    tune.play();
}

/**
 * @brief Calls uiBeep and waits untill the tune it done.
 * 
 * // TODO: This will probably need to be adapted / removed when button input is added.
 * 
 * @param beep 
 */
void uiBeepBlocking(uint16_t* beep) {
    uiBeep(beep);
    while(tune.isPlaying()) {
        tune.update();
        WATCHDOG_RESET;
    }
}

/**
 * @brief Reverts the current tune to the selected one.
 * 
 */
void revertToTune() {
    tune.setCallOnStop(NULL);
    tune.stop();
    // If in warble, mode, don't do anything as the flashLoader object isn't used for that and will be set before next use.
#ifdef ENABLE_WARBLE
    if(curTune != tuneCount) {
        // Normal tune playing mode
        flashLoader.setTune((uint16_t*)pgm_read_word(&(tunes[curTune])));
        tune.spool();
    }
#else
    flashLoader.setTune((uint16_t*)pgm_read_word(&(tunes[curTune])));
#endif
}

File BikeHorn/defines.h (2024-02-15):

/** defines.h
 * Definitions and settings for the BikeHorn.
 * 
 * For more details, see README.md or go to
 * https://github.com/jgOhYeah/BikeHorn
 * 
 * Written by Jotham Gates
 * Last modified 27/06/2023
 */

#pragma once
#define VERSION "1.4.1"

/**
 * @brief Pins and system setup
 * 
 */
#define PIEZO_PIN 9 // Fixed as PB1 (Pin 9 on Arduino Nano)
#define BOOST_PIN 11 // Fixed as PB3 (Pin 11 on Arduino Nano)
#define LED_EXTERNAL 7
#define BUTTON_HORN 2 // Needs to be interrupt capable (pin 2 or 3)
#define BUTTON_MODE 3 // Needs to be interrupt capable (pin 2 or 3)

#define SERIAL_BAUD 38400

#define IDLE_DUTY 5 // 9.4% duty cycle, keeps the voltage up when not playing
#define MIDI_CHANNEL 0 // Zero indexed, so many software shows ch. 0 as ch. 1
#define DEBOUNCE_TIME 20

// Watchdog timer to reduce lockups with a flat battery / unstable power supply
#define ENABLE_WATCHDOG_TIMER // DO NOT enable this (uncomment it) for Arduinos running the older (pre optiboot) bootloader as this will cause lockups

/**
 * @brief Warble mode settings
 * 
 */
#define ENABLE_WARBLE // Define this to add a warble sound as a final tune (like various burgler alarms, sirens and
                      // existing HPV horns)
#define WARBLE_LOWER 3000 // Lower frequency (Hz)
#define WARBLE_UPPER 3800 // Upper frequency (Hz)
#define WARBLE_RISE 15000 // Up chirp time (ms)
#define WARBLE_FALL 50000 // Down chirp time (ms)
#define WARBLE_STEP 10 // Number of timer 1 counts to step at a time (need to keep time between steps high enough to not
                       // get bogged down as each update now takes ~100us with eeprom piecewise)

/**
 * @brief Logging and EEPROM settings
 * 
 */
#define LOG_RUN_TIME // Define this if you want to keep a record of run time when in horn mode for battery usage analysis.
#define EEPROM_PIECEWISE_SIZE 81 // 1 length byte + 10 linear functions for a piecewise function
#define EEPROM_TIMER1_PIECEWISE 0x35e // Near the end so that the wear levelling can have the start
#define EEPROM_TIMER2_PIECEWISE EEPROM_TIMER1_PIECEWISE + EEPROM_PIECEWISE_SIZE
#define EEPROM_PIECEWISE_MAX_LENGTH 10 // Max number of functions piecewise function for sanity checking before allocating ram.

/**
 * @brief User interface
 * 
 */
#define LONG_PRESS_TIME 2000
#define MENU_TIMEOUT 30000

/**
 * @brief Accelerometer
 * 
 */
#define ACCEL_INSTALLED
#define ACCEL_X_PIN A4
#define ACCEL_Y_PIN A3
#define ACCEL_Z_PIN A2
#define ACCEL_POWER_PIN A5
#define ACCEL_PINS_SLEEP_MODE 0b00000000 // Input or output
#define ACCEL_PINS_SLEEP_STATE 0b11000011 // Pulled high (potentially through a resistor) or low.

/**
 * @brief Other defines
 * 
 */
#define WELCOME_MSG "Bike horn V" VERSION " started. Compiled " __TIME__ ", " __DATE__
#define MANUAL_CUTOFF // Allow notes to be stopped as we aren't using tone() to make the noises.
#define ENABLE_CALLBACKS
#define DEFAULT_TEMPO 120 // UI beeps
#define IS_PRESSED(PIN) !digitalRead(PIN) // Macro to make things a little clearer

// Stores which pin was responsible for waking the system up.
enum Buttons {PRESSED_NONE, PRESSED_HORN, PRESSED_MODE};

/**
 * @brief Libraries to include
 * 
 */
#include <cppQueue.h>
#include <LowPower.h>
#include <TunePlayer.h>
#include <EEPROM.h>

// Only needed for the watchdog timer (DO NOT enable for Arduinos with the old bootloader).
#ifdef ENABLE_WATCHDOG_TIMER
    #include <avr/wdt.h>
    #define WATCHDOG_ENABLE wdt_enable(WDTO_4S)
    #define WATCHDOG_DISABLE wdt_disable()
    #define WATCHDOG_RESET wdt_reset()
#else
    #define WATCHDOG_ENABLE
    #define WATCHDOG_DISABLE
    #define WATCHDOG_RESET
#endif

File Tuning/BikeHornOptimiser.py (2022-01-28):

#!/usr/bin/env python3
"""BikeHornOptimiser.py
An application for optimising the piezo and boost duty cycles of the bike horn for maximum volume.

For more details, see Readme.md or go to
https://github.com/jgOhYeah/BikeHorn/tree/main/Tuning

Written by Jotham Gates
Last modified 28/02/2022
"""
# GUI libraries
import tkinter as tk                    
from tkinter import ttk
from tkinter import filedialog as fd
import tkinter.messagebox as tkmb
import webbrowser # For opening the help link

# Graphs
from matplotlib.figure import Figure
from mpl_toolkits.mplot3d import Axes3D
from matplotlib.backends.backend_tkagg import FigureCanvasTkAgg, NavigationToolbar2Tk
from matplotlib.patches import Patch
from matplotlib.lines import Line2D

# Serial
import serial.tools.list_ports
from serial.serialutil import SerialException
import serial

# Sound
import sounddevice as sd

# Optimising
import piecewise_regression # https://github.com/chasmani/piecewise-regression
import fractions
import math

# General
import time
import numpy as np
import threading
from typing import Iterable, Tuple
import datetime

# TODO: Load / save a default settings file automatically (not necessary, but might be convenient)
# TODO: Standard deviation / different from those around a data point as a measure of uncertainty when fitting to avoid noise
# TODO: Cope with someone trying to test, optimise and upload at the same time
# TODO: Measure voltage as well
# TODO: Semi - Random / non sequential order of testing

name = "Bike Horn Optimiser Tool"
version = "1.0.1"

# For python 3.6 (https://stackoverflow.com/a/52440947)
class Spinbox(ttk.Entry):
    def __init__(self, master=None, **kw):
        super().__init__(master, "ttk::spinbox", **kw)
    def set(self, value):
        self.tk.call(self._w, "set", value)

class Logging():
    """Class for logging events and displaying them in appropriate locations
    """
    def __init__(self, gui=None) -> None:
        self._gui = gui

    def set_gui(self, gui=None) -> None:
        self._gui = gui

    def info(self, msg="", end="\n", dialog=False) -> None:
        print(msg, end=end)
        if self._gui:
            self._gui.add_monitor_text(msg, end)
            if dialog:
                self._gui.info_dialog(msg)

    def warning(self, msg="") -> None:
        warning_msg = "WARNING: {}".format(msg)
        print(warning_msg)
        if self._gui:
            self._gui.add_monitor_text(warning_msg, tag="warning")
            # self.gui.warning_dialog(msg)
    
    def error(self, msg="") -> None:
        error_msg = "ERROR: {}".format(msg)
        print(error_msg)
        if self._gui:
            self._gui.add_monitor_text(error_msg, tag="error")
            self._gui.error_dialog(msg)

class DataManager():
    """Class to handle all data and the loading and saving of it
    """
    def __init__(self, logging):
        self._filename = datetime.datetime.now().strftime("%Y%m%d_%H%M_BikeHornTestResults.npz")
        self._logging = logging
        self._to_call_on_update_sound = []
        self._to_call_on_update_settings = []
        self._to_call_on_update_metadata = []
        self._settings = {}
        self._sound_data = []
        self._metadata = {}

    def get_filename(self):
        """Gets the filename for the current file (or an autogenerated one if not set)

        Returns:
            str: filename
        """
        return self._filename

    def set_filename(self, filename):
        """Sets the filename to use

        Args:
            filename (str): the filename to use
        """
        self._filename = filename
    
    def save_data(self, backup=False):
        """Writes the file containing the data
        """
        filename = self.get_filename()
        extra_log_info = ""
        if backup:
            filename = "{}_BACKUP".format(filename)
            extra_log_info = " (as a backup)"

        self._generate_metadata(backup)
        self._logging.info("Writing {}{}".format(filename, extra_log_info))
        np.savez_compressed(filename, sound_data=self._sound_data, settings=self._settings, metadata=self._metadata)
    
    def save_optimisations(self, piezo, boost):
        # TODO
        pass

    def open(self, filename):
        self._logging.info("Opening {}".format(filename))
        # Load the file
        try:
            data = np.load(filename, allow_pickle=True)
        except (FileNotFoundError, OSError):
            self._logging.error("The select file does not exist or could not be opened.")
        else:
            # Find any metadata and print it
            if "metadata" in data:
                self._logging.info("Metadata found")
                self._metadata = data["metadata"][()]
                self._call_to_update_metadata()

            # Check all required data is present
            if not "sound_data" in data or not "settings" in data:
                self._logging.error("There was an issue opening the file. Either 'sound_data' or 'settings' is missing. Are you sure this is a valid file?")
                return

            # Unpacking tha data part
            self._sound_data = data["sound_data"][()] # Cope with 0d arrays
            self._settings = data["settings"][()]

            # Notify stuff that needs to know
            self._call_to_update_settings()
            self._call_to_update_sound()
    
    def set_settings(self, settings):
        self._settings = settings
        self._call_to_update_settings()
    
    def get_settings(self):
        return self._settings

    def get_metadata(self):
        return self._metadata

    def get_sound_data(self):
        return self._sound_data

    def set_sound_data(self, new_data):
        self._sound_data = new_data
        self._call_to_update_sound()

    def clear_data(self):
        self._sound_data = []
        self._call_to_update_sound()

    def register_call_on_update(self, method, call_on_sound_data=True, call_on_settings_data=True, call_on_metadata=False):
        """Registers a function to be called when the data is updated
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

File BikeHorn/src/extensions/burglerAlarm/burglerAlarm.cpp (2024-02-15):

#include "Arduino.h"
/** burglerAlarm.cpp
 * Requires an accelerometer by installed.
 * When activated, monitors for movement and sets off the siren if too much
 * movement is detected.
 * 
 * Written by Jotham Gates
 * Last modified 27/01/2023
 */

#include "burglerAlarm.h"

// Global variables that are accessed.
extern TunePlayer tune;
extern BikeHornSound piezo;
extern volatile Buttons wakePin;
extern void startBoost();
extern void stopBoost();
extern void uiBeep(uint16_t* beep);
extern void uiBeepBlocking(uint16_t* beep);
extern void wakeGPIO();
extern void sleepGPIO();
extern void wakeUpEnable();
extern void wakeUpDisable();

// Statis state members
StatesList State::states;
CodeEntry* State::codeEntry;
Acceleromenter* State::accelerometer;

BurglerAlarmExtension::BurglerAlarmExtension() {
    // Add the burgler alarm function pointer to the menu
    menuActions.length = 1;
    menuActions.array = (MenuItem*)malloc(sizeof(MenuItem));
    menuActions.array[0] = (MenuItem)&BurglerAlarmExtension::stateMachine;
}

void BurglerAlarmExtension::onStart() {
    stateMachine();
}

void BurglerAlarmExtension::stateMachine() {
    Serial.println(F("Starting state machine"));
    Serial.flush();

    // Create and add the states
    StateInit init;
    State::states.init = &init;
    StateSleep sleep;
    State::states.sleep = &sleep;
    StateAwake awake;
    State::states.awake = &awake;
    StateAlert alert;
    State::states.alert = &alert;
    StateCountdown countdown;
    State::states.countdown = &countdown;
    StateSiren siren;
    State::states.siren = &siren;

    // Add the unlock code
    CodeEntry codeEntry(MY_CODE);
    State::codeEntry = &codeEntry;

    // Add the accelerometer control
    Acceleromenter accelerometer;
    State::accelerometer = &accelerometer;

    // Run the state machine
    State* current = &init;
    while (current) {
        wakeGPIO(); // To enable serial
        Serial.println(current->name); // NOTE: For debugging
        current = current->enter();
    }

    // Tidy up
    accelerometer.stop();
    Serial.println(F("Exiting burgler alarm"));
    // TODO: Beep?

}

State* StateInit::enter() {
    // TODO: Button to cancel
    wakeUpEnable(); // Enable waking up and cancelling if pressed.
    accelerometer->start();
    for (uint8_t i = 0; i != PREVIOUS_RECORDS && wakePin == PRESSED_NONE; i++) {
        WATCHDOG_RESET;
        LowPower.powerDown(SLEEP_250MS, ADC_ON, BOD_OFF); // Also time for startup
        accelerometer->calibrate();
    }
    wakeUpDisable();
    wakeGPIO();
    // Check if the alarm entry has been cancelled.
    if(wakePin == PRESSED_NONE) {
        // Not touched, go to alarm
        uiBeepBlocking(const_cast<uint16_t*>(beeps::acknowledge));
        return states.sleep;
    } else {
        // Touched, cancel alarm
        uiBeepBlocking(const_cast<uint16_t*>(beeps::cancel));
        return nullptr;
    }
}

State* StateSleep::enter() {
    // State setup
    sleepGPIO();
    wakeUpEnable();

    // Main loop
    do {
        WATCHDOG_RESET;

        // Shut down and sleep
        accelerometer->stop();
        LowPower.powerDown(SLEEP_1S, ADC_OFF, BOD_OFF);

        // Check the button wasn't pressed during the shutdown sleep
        if (wakePin != PRESSED_NONE) {
            break;
        }

        // Turn the accelerometer on and wait for it start up
        accelerometer->powerOn();
        LowPower.powerDown(SLEEP_250MS, ADC_OFF, BOD_OFF);

        // Take the reading
        accelerometer->startADC();
    } while (wakePin == PRESSED_NONE && !accelerometer->isMoved());

    // Exiting the state
    wakeUpDisable();
    if (wakePin == PRESSED_NONE) {
        // Button not pressed.
        return states.awake;
    } else {
        // Button pressed.
        return states.countdown;
    }
}

State* StateAwake::enter() {
    // Start up
    wakeUpEnable();
    accelerometer->powerOn();
    accelerometer->startADC();

    // Monitor the accelerometer at a higher rate for a while.
    for (uint8_t i = 0; i != IGNORE_CYCLES && wakePin == PRESSED_NONE; i++) {
        WATCHDOG_RESET;
        digitalWrite(LED_EXTERNAL, LOW);
        LowPower.powerDown(SLEEP_250MS, ADC_ON, BOD_OFF); // Also time for startup
        digitalWrite(LED_EXTERNAL, HIGH);
        accelerometer->isMoved(); // Ignore for a while
    }
    
    // Time spent or button pressed.
    wakeUpDisable();
    digitalWrite(LED_EXTERNAL, LOW);
    if (wakePin == PRESSED_NONE) {
        // Timed out.
        return states.alert;
    } else {
        // Button pressed.
        return states.countdown;
    }
}

State* StateAlert::enter() {
    // Start up
    wakeUpEnable();
    accelerometer->powerOn();
    accelerometer->startADC();

    // Monitor the accelerometer at a higher rate for a while.
    for (uint8_t i = 0; i != ALERT_CYCLES && wakePin == PRESSED_NONE; i++) {
        WATCHDOG_RESET;
        digitalWrite(LED_EXTERNAL, LOW);
        LowPower.powerDown(SLEEP_250MS, ADC_ON, BOD_OFF); // Also time for startup
        digitalWrite(LED_EXTERNAL, HIGH);
        if (accelerometer->isMoved()) {
            wakeUpDisable();
            return states.countdown;
        }
    }

    // Not moved. Timed out or button pressed.
    wakeUpDisable();
    if (wakePin == PRESSED_NONE) {
        // Timed out.
        return states.sleep;
    } else {
        // Button pressed.
        return states.countdown;
    }
}

State* StateCountdown::enter() {
    // Starting code entry / countdown
    codeEntry->start();
    if(codeEntry->playWithTune(const_cast<uint16_t*>(alarmCountdownTune))) {
        // Code successful
        Serial.println(F("Success"));
        return nullptr; // To fall through and exit the state machine
    } else {
        // Timed out or fail
        Serial.println(F("Fail"));
        return states.siren;
    }
}

State* StateSiren::enter() {
    Serial.println(F("Siren"));
    // Am not restarting code entry as there are situations where the deadline
    // is just missed and the siren starts, so keep going to finish.
    startBoost();
    if(codeEntry->playWithTune(const_cast<uint16_t*>(BURGLER_ALARM_TUNE))) {
        // Code entered successfully
        return nullptr; // Exit the alarm.
    } else {
        return states.sleep; // Wait for another detection.
    }
}

CodeEntry::CodeEntry(const uint16_t code) : m_code(code) {
    start();
}

CodeEntry::CodeEntry(const uint16_t pin, const uint8_t length) : m_code(ENCODE_CODE(pin, length)) {
    start();
}

void CodeEntry::start() {
    m_charsLeft = m_code & 0xf;
    m_inputted = 0;
    m_lastPressedTime = millis() - DEBOUNCE_TIME - 1; // Subtracting debounce time so that the button being pressed at the start is recognised
}

bool CodeEntry::add(bool character) {
    m_charsLeft--;
    if(m_charsLeft >= 0) {
        m_inputted |= character << m_charsLeft;
        return m_charsLeft == 0;
    }
    return true;
}
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

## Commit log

2021-06-23 Added files and organising
    [BikeHornPCB.kicad_pcb, BikeHornPCB.sch, HandlebarButton.FCStd]
2021-07-08 Switch built into handlebar clamp and stl export
    [MainBody-CarrierFrame.stl, MainBody-HandlebarClampSwitch.stl, MainBody-HandlebarGuide.stl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]
2021-07-10 Added switch in clamp & made intellisense happy
    [MainBody-CarrierFrame.stl, MainBody-HandlebarClampSwitch.stl, MainBody-HandlebarGuide.stl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]
2021-07-13 Added docs, runtime logging, revised PCB to fix issues from first version built
    [BikeHornPCB.kicad_pcb, BikeHornPCB.sch]
2021-07-15 Added eeprom reset and gif
    [BikeHorn.ino, defines.h]
2021-09-19 Warble works but lots of glitches in warble sound
    [BikeHorn.ino, defines.h]
2021-09-19 Warble works with a few less glitches now and new song
    [BikeHorn.ino, defines.h]
2021-10-01 Using interrupts to make warble work without double buffering and without glitches
2021-10-01 stopSound now shuts down timer 1 interrupts
2021-11-25 Added watchdog timer support to reduce embarrassment at low battery levels
2021-12-22 Fixed display data crash on slider adjust, removed adc graph as no longer part of hw
2021-12-28 Running test in its own thread and hopefully fixed audio shutdown crash
    [BikeHornOptimiser.py]
2022-01-03 Uploading to Arduino finally works
2022-01-10 Mostly fixed timer values display issues
    [BikeHornOptimiser.py]
2022-01-23 Fixed sometimes not clipping and hopefully stopped multiple error dialogs freezing application
    [BikeHornOptimiser.py]
2022-01-28 Added examples, fixed bug opening aborted test file, cleaning up
    [BikeHornOptimiser.py]
2022-07-01 PCD saved for KiCAD 6, added rescue files that should have been there all along
    [BikeHornPCB.kicad_pcb, BikeHornPCB.kicad_sch]
2022-07-02 Simple extensions framework added, not tested
2022-07-09 Fixed ui beeps and added voltage measurements
    [BikeHorn.ino, defines.h, extensionsManager.h]
2022-08-16 Started adding accelerometer
2022-08-22 Framework for improved state machine
2022-10-30 Added makefile for arduino-cli
2022-11-01 Moving to src folder, fixing includes to compile
    [BikeHorn.ino, burglerAlarm.cpp, defines.h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]
2022-11-06 Countdown with beep and code fail noise works
    [BikeHorn.ino, burglerAlarm.cpp]
2022-12-30 accelerometer null hypothesis works
2023-01-27 Button wakes up alarm
2023-06-27 Fixed ADC not being turned on to measure battery voltages
    [defines.h]
